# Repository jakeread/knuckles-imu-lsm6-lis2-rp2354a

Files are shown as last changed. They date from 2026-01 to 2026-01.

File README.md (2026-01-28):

# Knuckles Accelerometer Module

> An IMU using the LSM6DSV16X accelerometer, LIS2MDL magnetometer, and RP2354A microcontroller. 

| | |
| --- | --- |
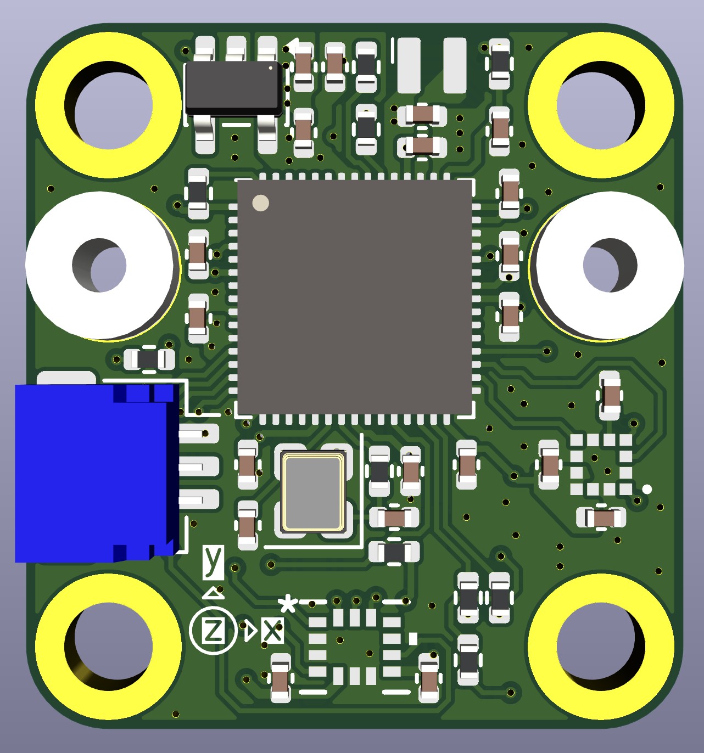
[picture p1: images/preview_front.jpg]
preview_front
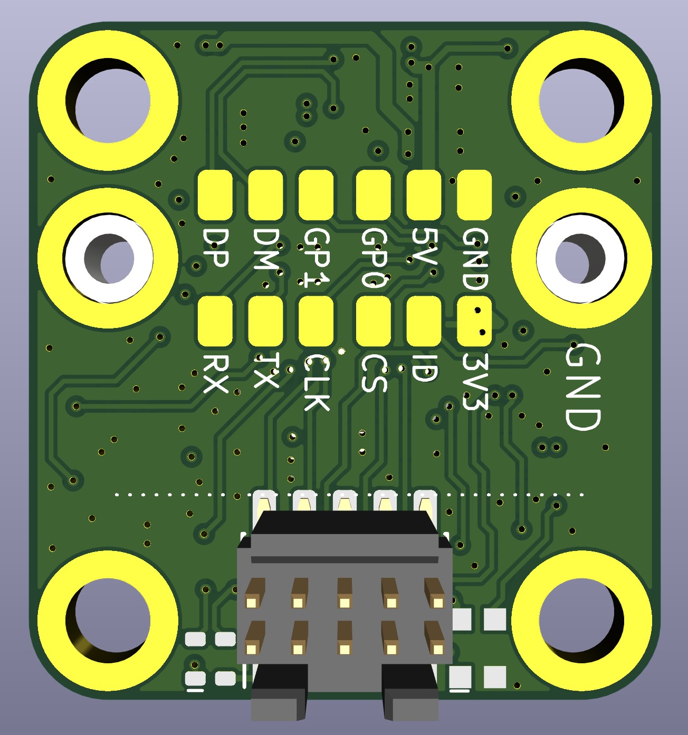
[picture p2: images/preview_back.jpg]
preview_back
|  |  |
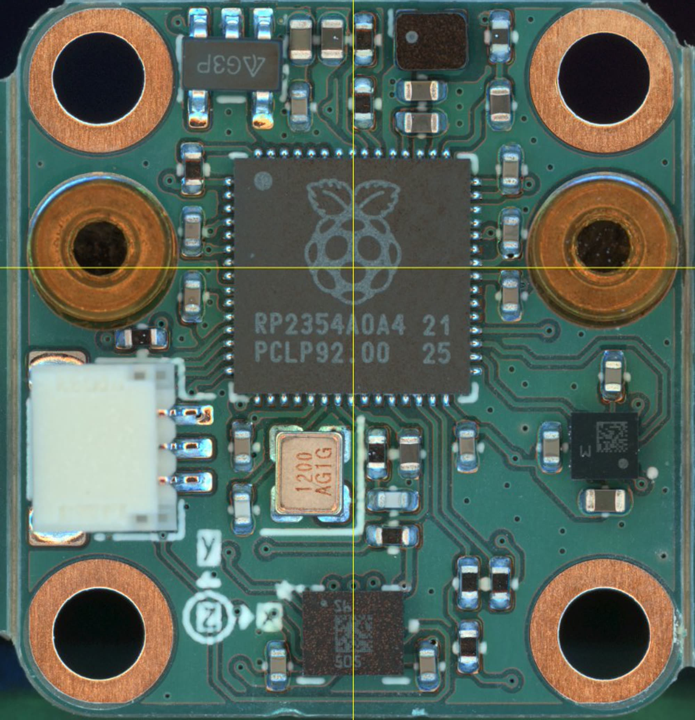
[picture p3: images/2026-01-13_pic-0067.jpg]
fab_front
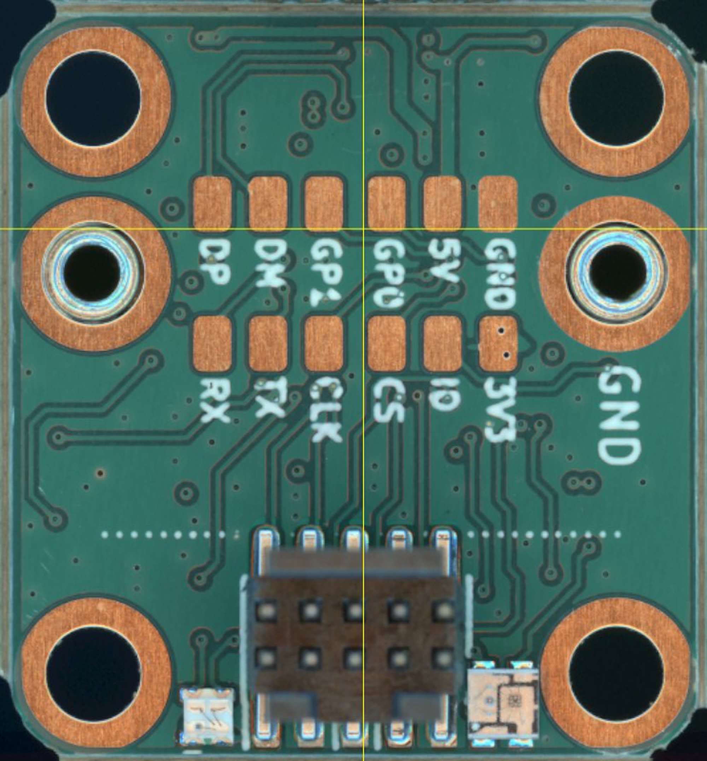
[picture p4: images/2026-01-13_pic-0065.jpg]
fab_back
|  |  |
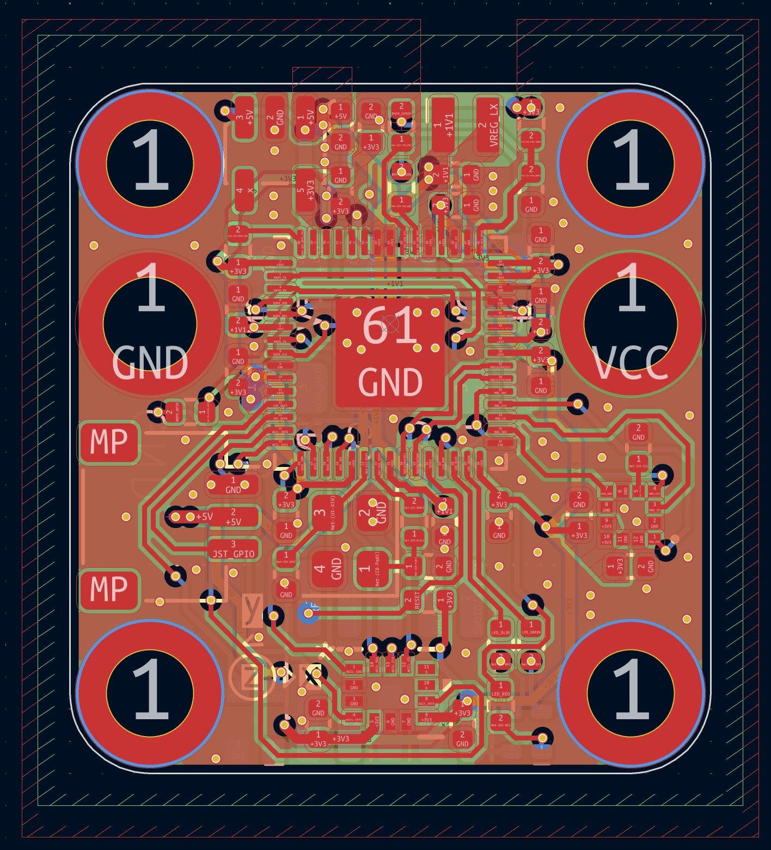
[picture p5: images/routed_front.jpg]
routed_front
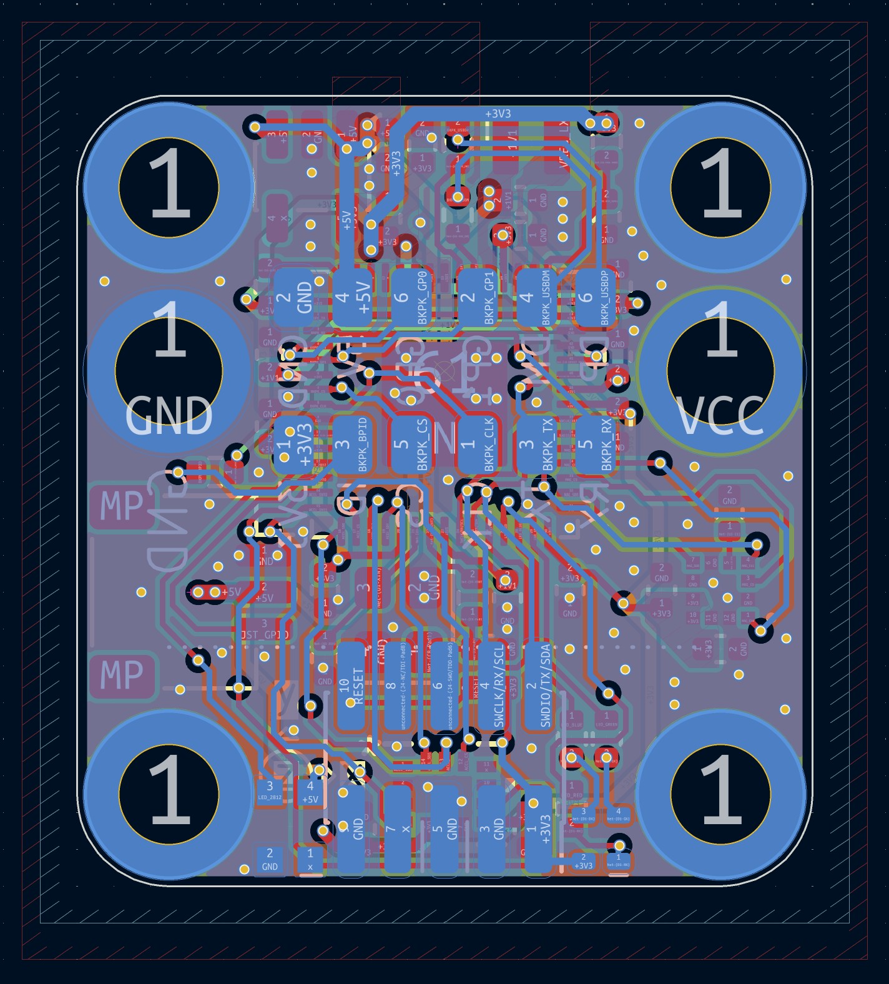
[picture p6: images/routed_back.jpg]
routed_back
|  |  |

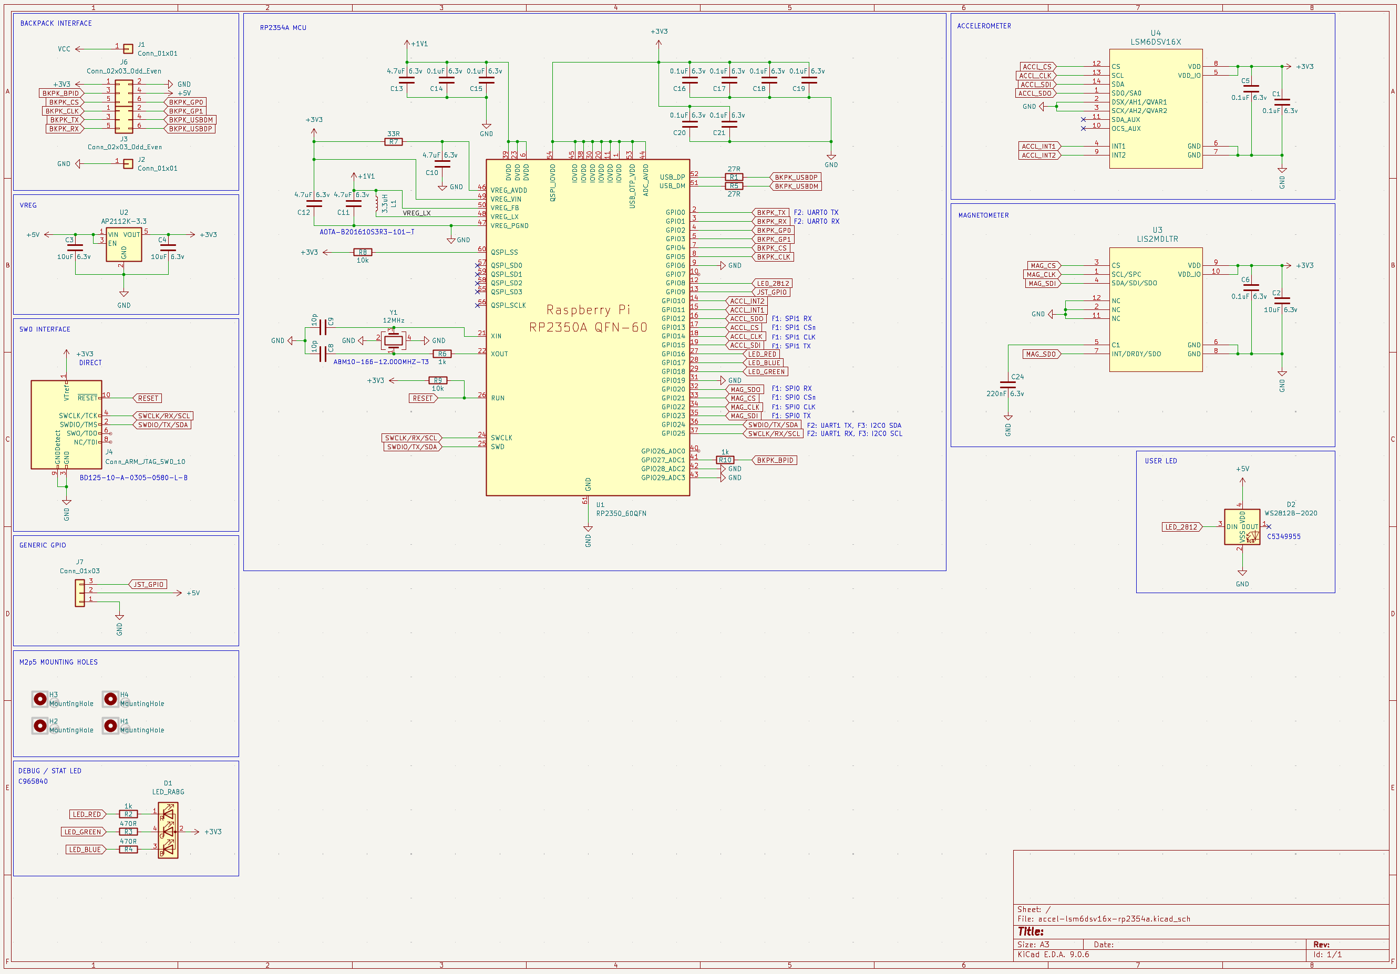
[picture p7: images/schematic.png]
schematic
  

## Functional Description

This is an IMU module that pairs the LSM6DSV16X accelerometer with an LIS2MDL magnetometer, using an RP2354A microcontroller. It is part of a larger family of modular circuits that I call `knuckles` and are used to build machine controllers. The `knuckles` system is not yet public. This IMU will be used to improve kinematic and frequency response models with higher frequency data than I can currently capture. 

The RP2354A is connected to the LSM6 and LIS2 via two indepentent SPI busses, and the LSM6's two interrupt lines are also routed back to the RP2354A. The board also includes an RGB LED (using GPIOs) for RTOS status indication, and a WS2812-based RGB LED for application status. 

The board is programmed with a standard 10-pin SWD connector. Communication is done through a `backpack` connection, which interfaces to modular PHY circuits; this is part of the `knuckles` system: the interface can be extended for UART, USB, CAN, Ethernet, or Wireless links. 

I have also included a generic GPIO output on a JST-SH connector for adhoc applications (it may be useful and there was space). 

## Enclosure

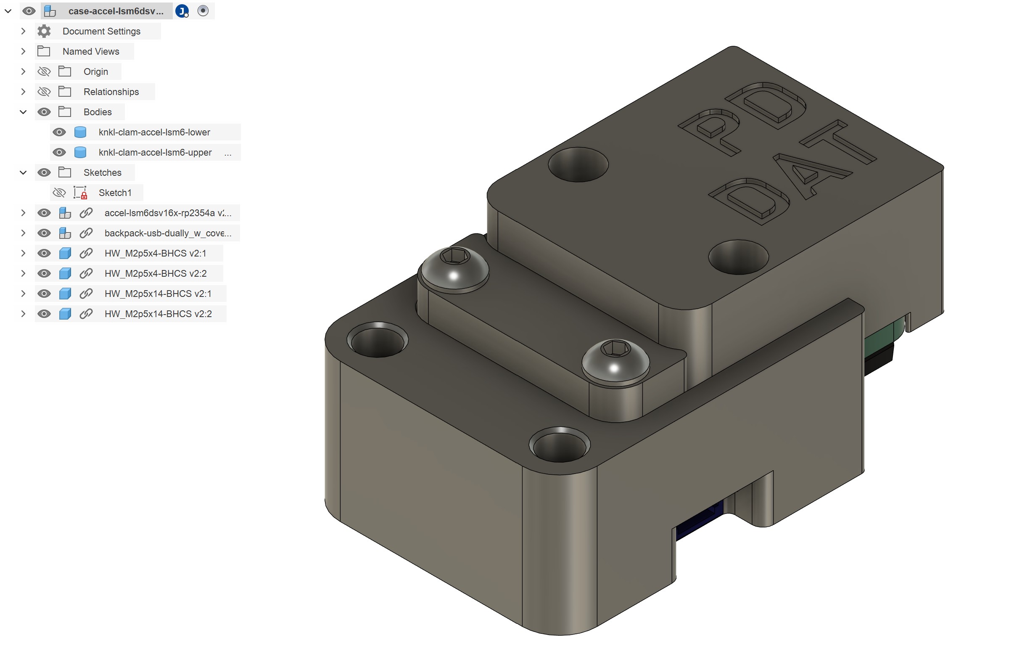
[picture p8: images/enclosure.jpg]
enclosure


The board can be mounted directly into a machine and enclosed there, or mounted into this enclosure and attached externally anywhere. This is intended to be printed in PETG and uses M2.5 hardware. 

## TODO

- bring up and test firmware

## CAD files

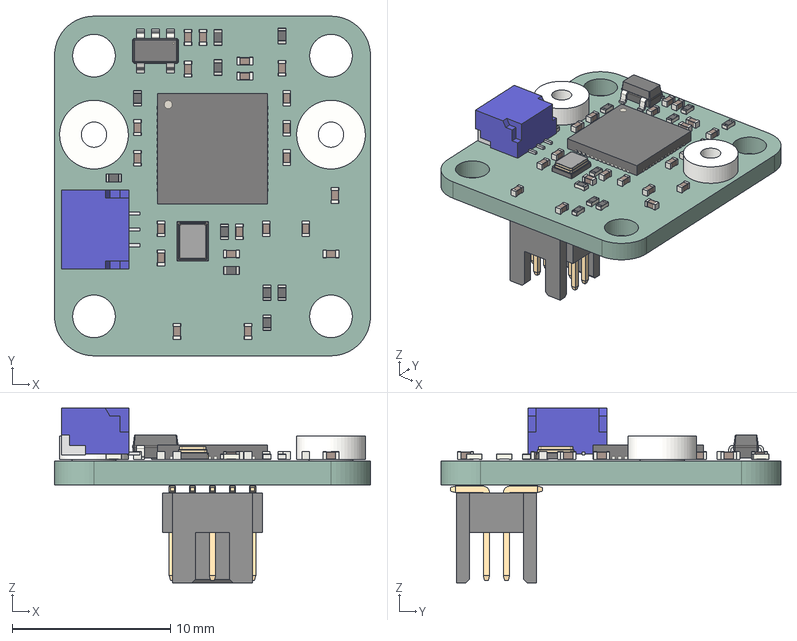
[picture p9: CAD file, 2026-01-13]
cad/accel-lsm6dsv16x-rp2354a.step
20.0 x 21.5 x 11.1 mm
C_0402_1005Metric x 21
R_0402_1005Metric x 10
Wurth_WA-SMST_M2_Thread_1.5mm_9774015243R x 2
QFN-56-1EP_7x7mm_P0.4mm_EP5.6x5.6mm
Crystal_SMD_2520-4Pin_2.5x2.0mm
SOT-23-5
JST_SH_SM03B-SRSS-TB_1x03-1MP_P1.00mm_Horizontal
PinHeader_2x05_P1.27_Vertical_SMD_Shrouded_BD125-10-A-0305-0580-L-B
accel-lsm6dsv16x-rp2354a_PCB

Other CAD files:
cad/case-accel-lsm6dsv16x-rp2354a.f3z

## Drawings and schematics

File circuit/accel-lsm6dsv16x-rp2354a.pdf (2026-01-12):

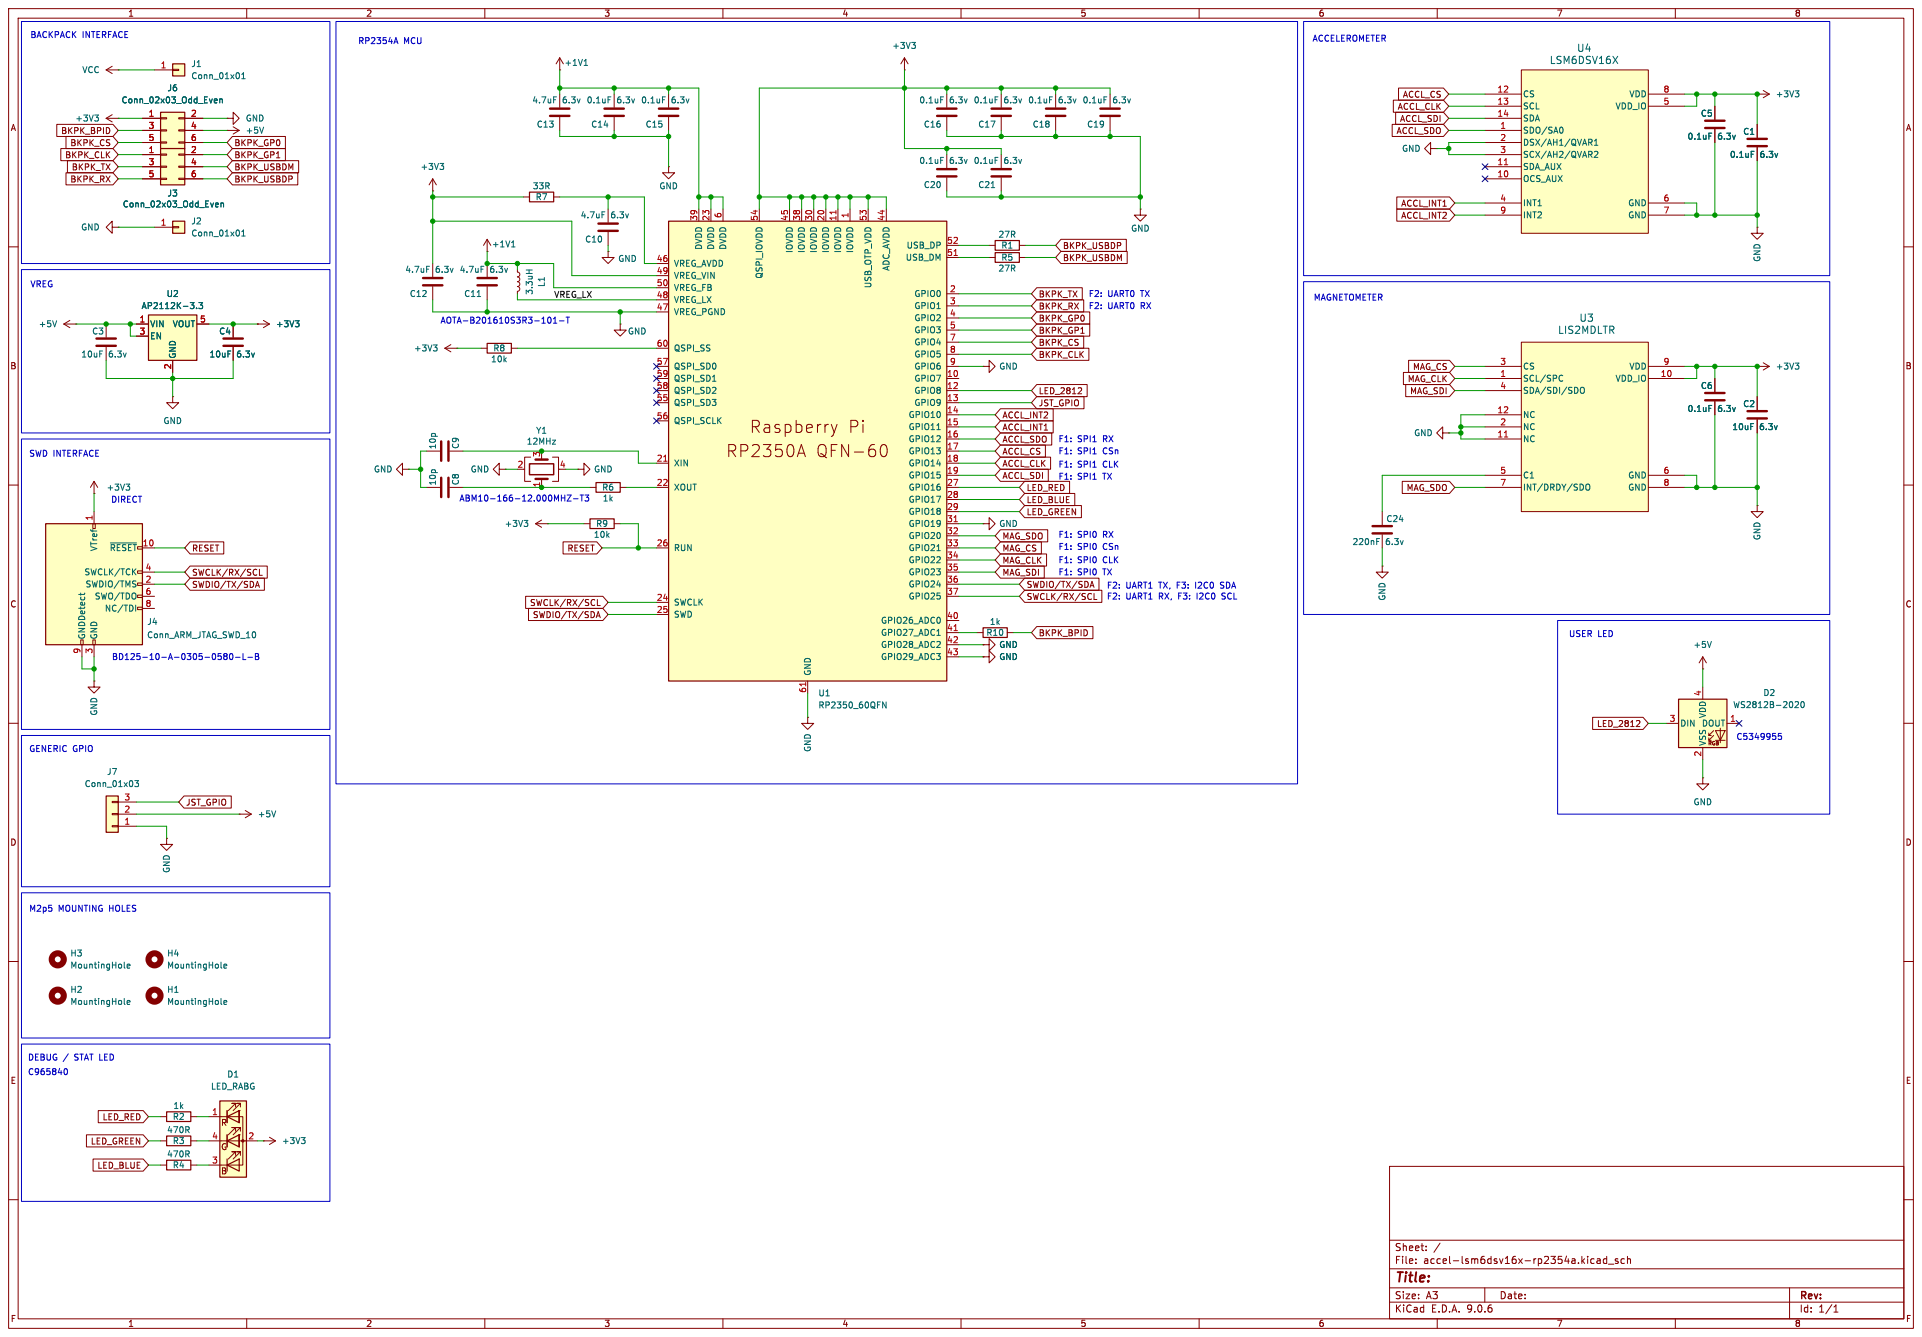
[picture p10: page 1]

ACCL_INT2 SWCLK/RX/SCL SWDIO/TX/SDA

6 QSPI_IOVDD 54 IOVDD 45 IOVDD 38 GND 61 IOVDD 30 IOVDD 20 IOVDD 11 IOVDD

2 VOUT 5 U2 AP2112K-3.3 +5V GND
F2: UART0 RX GENERIC GPIO
ABM10-166-12.000MHZ-T3 AOTA-B201610S3R3-101-T M2p5 MOUNTING HOLES DEBUG / STAT LED

3 ~{RESET}10 SWCLK/TCK 4 SWDIO/TMS 2 SWO/TDO 6 NC/TDI 8

Id: 1/1 Title: File: accel-lsm6dsv16x-rp2354a.kicad_sch Sheet: /

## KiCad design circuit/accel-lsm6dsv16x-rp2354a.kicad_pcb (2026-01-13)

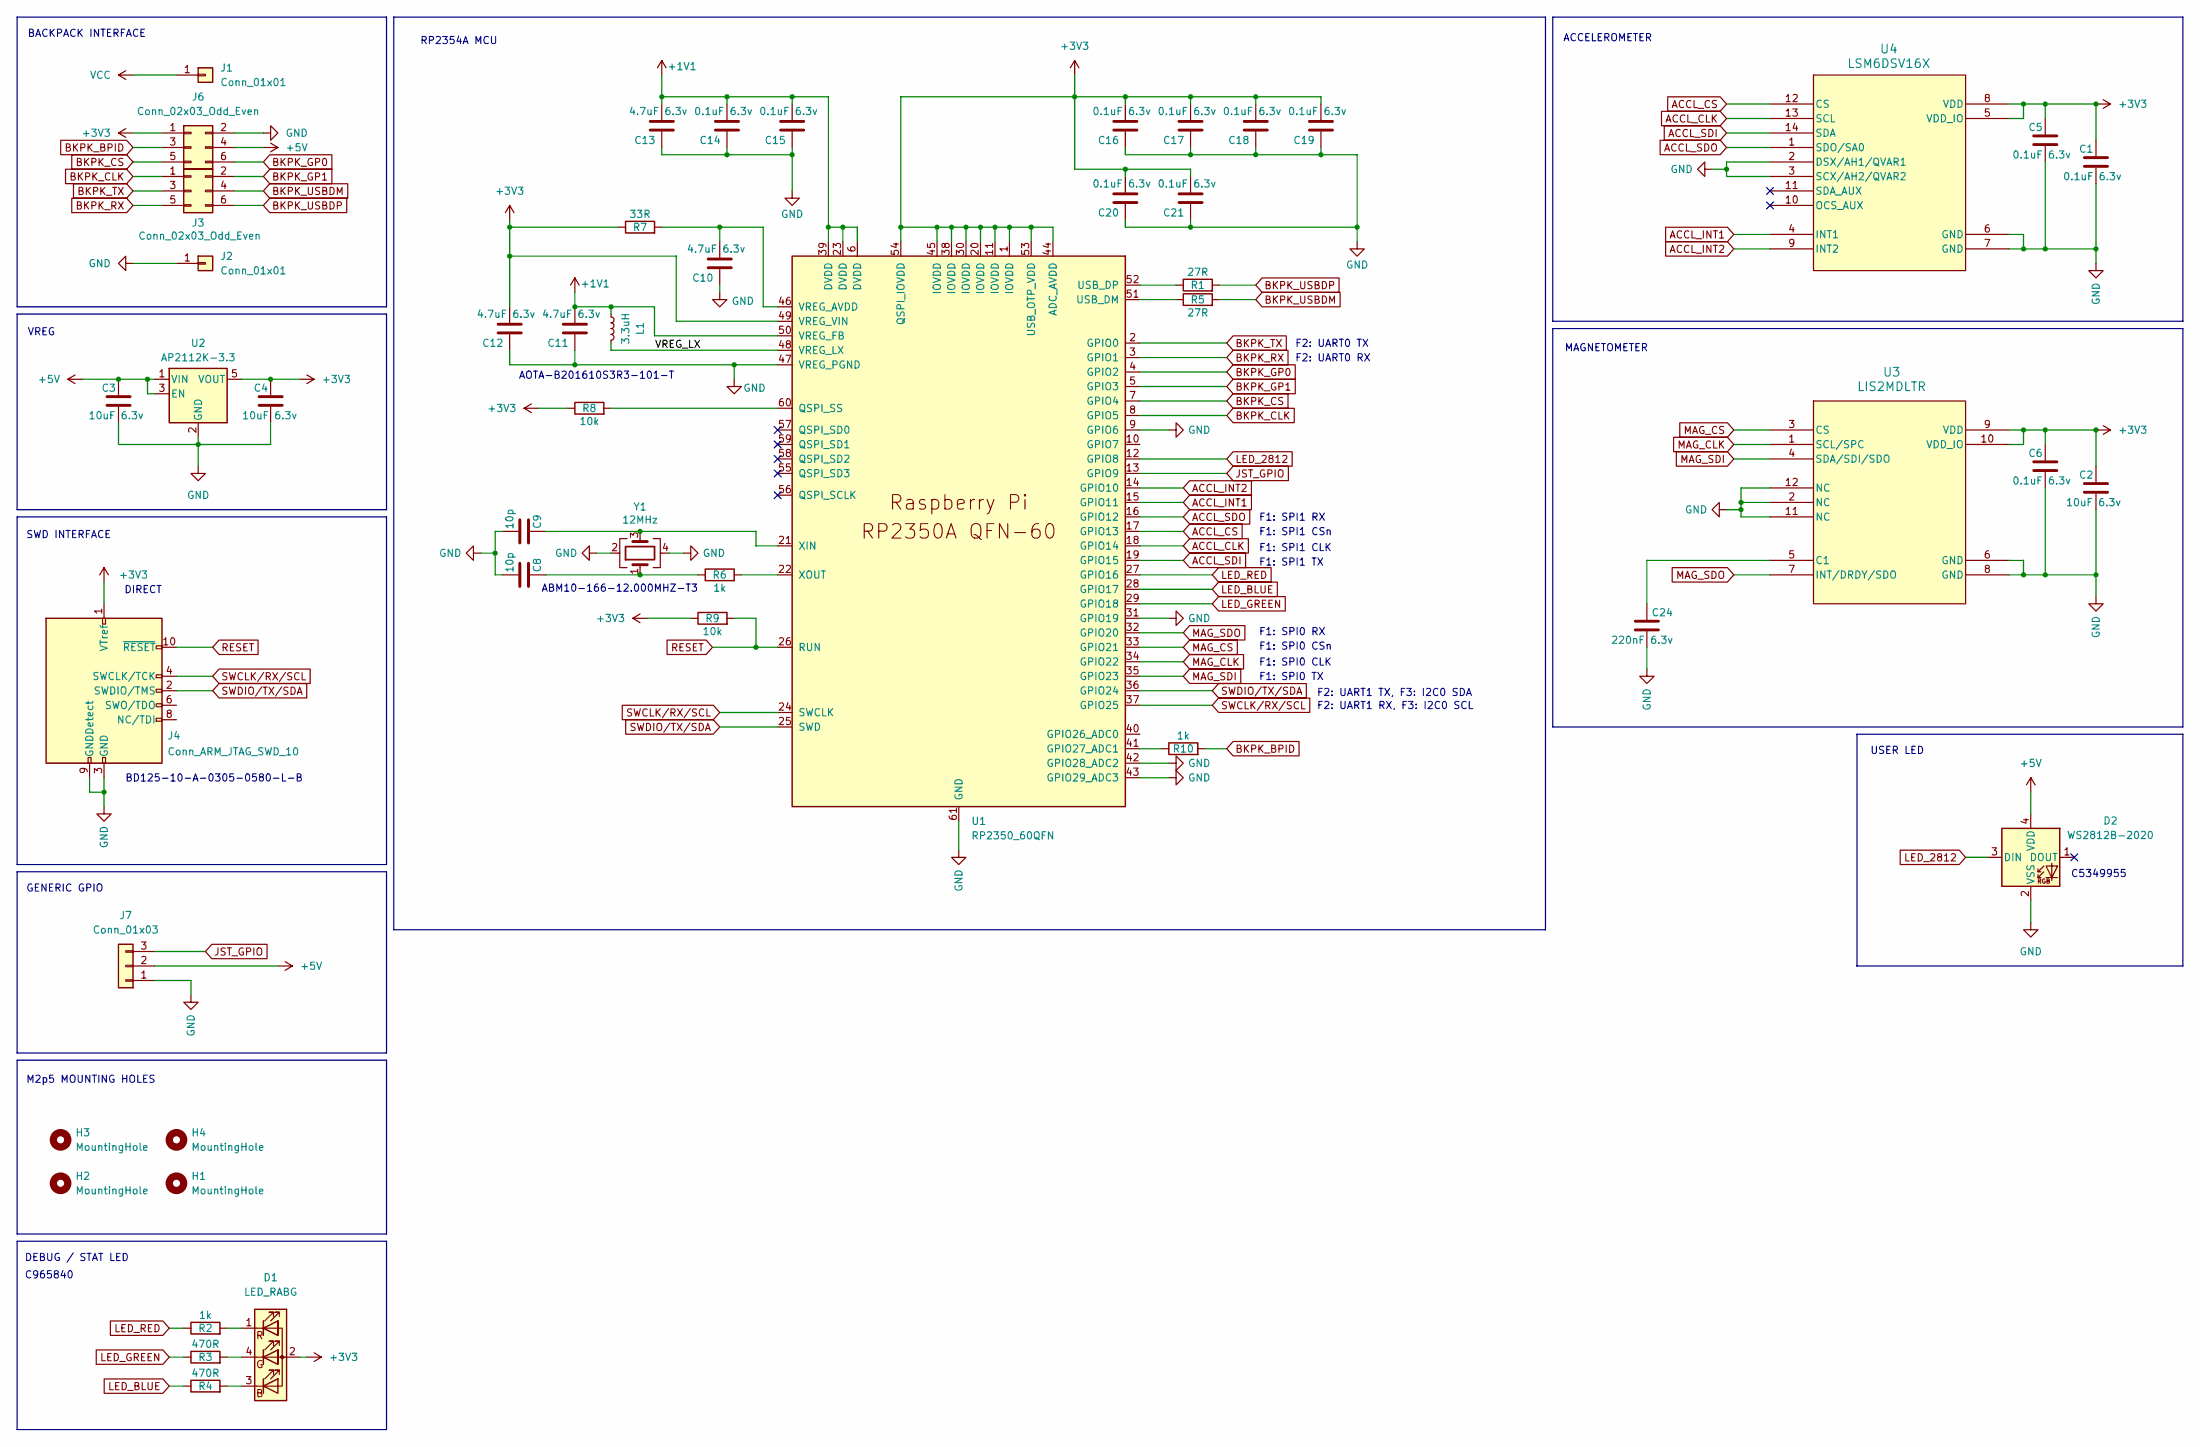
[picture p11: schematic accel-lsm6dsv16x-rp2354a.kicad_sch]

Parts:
C1, C5, C6, C14, C15, C16, C17, C18, C19, C20, C21: 0.1uF 6.3v; C_0402_1005Metric; MPN CC0402KRX7R5BB104
C2, C3, C4: 10uF 6.3v; C_0402_1005Metric; MPN MSASJ105CB5106MFNQ1D
C8, C9: 10p; C_0402_1005Metric; MPN CC0402JRNPO9BN100
C10, C11, C12, C13: 4.7uF 6.3v; C_0402_1005Metric; MPN CC0402MRX5R5BB475
C24: 220nF 6.3v; C_0402_1005Metric; MPN CC0402MRX5R5BB224
D1: LED_RABG; LED_RGB_1615; MPN XL-1615RGBC-RF; LCSC Part # C965840
D2: WS2812B-2020; LED_WS2812B-2020_PLCC4_2.0x2.0mm; MPN XL-2020RGBC-2812B; LCSC Part # C5349955
H1, H2, H3, H4: MountingHole; MountingHole_M2.5_Corner
J1, J2: Conn_01x01; Wurth_WA-SMST_M2_Thread_1.5mm_9774015243R; MPN SMTWEM215STR; DigiKey Part # 732-7069-6-ND
J3: Conn_02x03_Odd_Even; SpringTarget_2x03_Molex_0788641001; LCSC Part # DNP
J4: Conn_ARM_JTAG_SWD_10; PinHeader_2x05_P1.27mm_Vertical_SMD_Shrouded_BD125-10-A-030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; MPN FTSH-105-01-F-DV-K; LCSC Part # C5382952
J6: Conn_02x03_Odd_Even; SpringTarget_2x03_Molex_0788641001; Digikey Part # DNP
J7: Conn_01x03; JST_SH_SM03B-SRSS-TB_1x03-1MP_P1.00mm_Horizontal; MPN SM03B-SRSS-TB(LF)(SN); Digikey Part # 455-SM03B-SRSS-TBCT-ND
L1: 3.3uH; L_pol_2016; MPN AOTA-B201610S3R3-101-T; Digikey Part # AOTA-B201610S3R3-101-T
R1, R5: 27R; R_0402_1005Metric; MPN RC0402FR-0727RL
R2, R6, R10: 1k; R_0402_1005Metric; MPN RC0402FR-071KL
R3, R4: 470R; R_0402_1005Metric; MPN RC0402FR-07470RL
R7: 33R; R_0402_1005Metric; MPN RC0402FR-0733RL
R8, R9: 10k; R_0402_1005Metric; MPN RC0402FR-0710KL
U1: RP2350_60QFN; RP2350-QFN-60-1EP_7x7_P0.4mm_EP3.4x3.4mm; MPN RP2354A; LCSC Part # C41378174
U2: AP2112K-3.3; SOT-23-5; MPN AP2112K-3.3TRG1; LCSC Part # C51118
U3: LIS2MDLTR; LGA-12_2X2X1_STM; MPN LIS2MDLTR; Digikey Part # LIS2MDLTR
U4: LSM6DSV16X; LGA14_LSM6_STM; MPN LSM6DSV16XTR; Digikey Part # LSM6DSV16XTR
Y1: 12MHz; Crystal_SMD_2520-4Pin_2.5x2.0mm; MPN ABM10-166-12.000MHZ-T3; Digikey Part # 535-13520-1-ND

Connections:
+1V1: C11.2, C13.2, C14.2, C15.2, L1.1, U1.6 (DVDD), U1.23 (DVDD), U1.39 (DVDD), U1.50 (VREG_FB)
+3V3: C1.1, C2.1, C4.1, C5.1, C6.1, C12.2, C16.2, C17.2, C18.2, C19.2, C20.2, C21.2, D1.2 (A), J4.1 (VTref), J6.1, R7.1, R8.1, R9.1, U1.1 (IOVDD), U1.11 (IOVDD), U1.20 (IOVDD), U1.30 (IOVDD), U1.38 (IOVDD), U1.44 (ADC_AVDD), U1.45 (IOVDD), U1.49 (VREG_VIN), U1.53 (USB_OTP_VDD), U1.54 (QSPI_IOVDD), U2.5 (VOUT), U3.9 (VDD), U3.10 (VDD_IO), U4.5 (VDD_IO), U4.8 (VDD)
+5V: C3.1, D2.4 (VDD), J6.4, J7.2, U2.1 (VIN), U2.3 (EN)
/VREG_LX: L1.2, U1.48 (VREG_LX)
ACCL_CLK: U1.18 (GPIO14), U4.13 (SCL)
ACCL_CS: U1.17 (GPIO13), U4.12 (CS)
ACCL_INT1: U1.15 (GPIO11), U4.4 (INT1)
ACCL_INT2: U1.14 (GPIO10), U4.9 (INT2)
ACCL_SDI: U1.19 (GPIO15), U4.14 (SDA)
ACCL_SDO: U1.16 (GPIO12), U4.1 (SDO/SA0)
BKPK_BPID: J6.3, R10.2
BKPK_CLK: J3.1, U1.8 (GPIO5)
BKPK_CS: J6.5, U1.7 (GPIO4)
BKPK_GP0: J6.6, U1.4 (GPIO2)
BKPK_GP1: J3.2, U1.5 (GPIO3)
BKPK_RX: J3.5, U1.3 (GPIO1)
BKPK_TX: J3.3, U1.2 (GPIO0)
BKPK_USBDM: J3.4, R5.2
BKPK_USBDP: J3.6, R1.2
GND: C1.2, C2.2, C3.2, C4.2, C5.2, C6.2, C8.2, C9.2, C10.1, C11.1, C12.1, C13.1, C14.1, C15.1, C16.1, C17.1, C18.1, C19.1, C20.1, C21.1, C24.2, D2.2 (VSS), J2.1, J4.3 (GND), J4.5 (GND), J4.9 (GNDDetect), J6.2, J7.1, U1.9 (GPIO6), U1.31 (GPIO19), U1.42 (GPIO28_ADC2), U1.43 (GPIO29_ADC3), U1.47 (VREG_PGND), U1.61 (GND), U2.2 (GND), U3.2 (NC), U3.6 (GND), U3.8 (GND), U3.11 (NC), U3.12 (NC), U4.2 (DSX/AH1/QVAR1), U4.3 (SCX/AH2/QVAR2), U4.6 (GND), U4.7 (GND), Y1.2, Y1.4
JST_GPIO: J7.3, U1.13 (GPIO9)
LED_2812: D2.3 (DIN), U1.12 (GPIO8)
LED_BLUE: R4.1, U1.28 (GPIO17)
LED_GREEN: R3.1, U1.29 (GPIO18)
LED_RED: R2.1, U1.27 (GPIO16)
MAG_CLK: U1.34 (GPIO22), U3.1 (SCL/SPC)
MAG_CS: U1.33 (GPIO21), U3.3 (CS)
MAG_SDI: U1.35 (GPIO23), U3.4 (SDA/SDI/SDO)
MAG_SDO: U1.32 (GPIO20), U3.7 (INT/DRDY/SDO)
unnamed: C8.1, R6.1, Y1.1
unnamed: D1.3 (BK), R4.2
unnamed: D1.4 (GK), R3.2
unnamed: D1.1 (RK), R2.2
unnamed: R10.1, U1.41 (GPIO27_ADC1)
unnamed: R8.2, U1.60 (QSPI_SS)
unnamed: R5.1, U1.51 (USB_DM)
unnamed: R1.1, U1.52 (USB_DP)
unnamed: C10.2, R7.2, U1.46 (VREG_AVDD)
unnamed: C9.1, U1.21 (XIN), Y1.3
unnamed: R6.2, U1.22 (XOUT)
unnamed: C24.1, U3.5 (C1)
RESET: J4.10 (~RESET), R9.2, U1.26 (RUN)
SWCLK/RX/SCL: J4.4 (SWCLK/TCK), U1.24 (SWCLK), U1.37 (GPIO25)
SWDIO/TX/SDA: J4.2 (SWDIO/TMS), U1.25 (SWD), U1.36 (GPIO24)
VCC: J1.1

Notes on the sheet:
C965840
F1: SPI0 CSn
RP2354A MCU
C5349955
M2p5 MOUNTING HOLES
F2: UART1 RX, F3: I2C0 SCL
F1: SPI1 CSn
BD125-10-A-0305-0580-L-B
GENERIC GPIO
USER LED
MAGNETOMETER
F1: SPI1 TX
DIRECT
F1: SPI0 RX
VREG
F1: SPI0 CLK
DEBUG / STAT LED
F1: SPI1 RX
F2: UART0 RX
SWD INTERFACE
F2: UART0 TX
F1: SPI0 TX
BACKPACK INTERFACE
F1: SPI1 CLK
ABM10-166-12.000MHZ-T3
AOTA-B201610S3R3-101-T
F2: UART1 TX, F3: I2C0 SDA
ACCELEROMETER

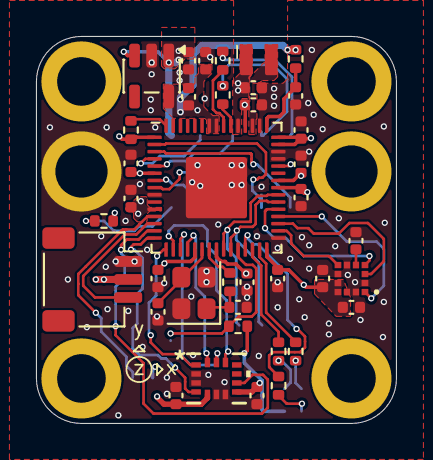
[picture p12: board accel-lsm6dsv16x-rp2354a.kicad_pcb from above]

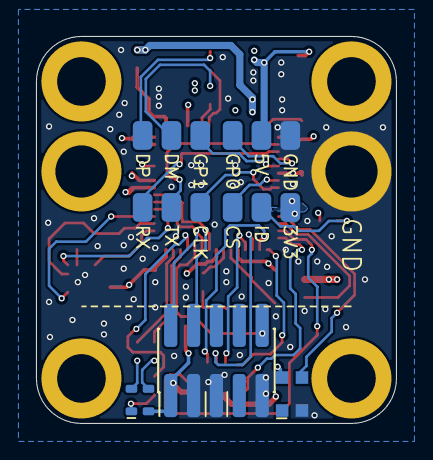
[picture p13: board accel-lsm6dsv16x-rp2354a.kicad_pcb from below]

Board: 4 copper layers, 20.0 x 21.5 mm, 49 parts (5 on the bottom side), 44 nets.

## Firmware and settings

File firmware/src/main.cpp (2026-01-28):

#include "board_hal.h"
#include "SparkFun_LSM6DSV16X.h"
#include <SPI.h>

// TODO
// notes in `maxl-dev/log/2025-11_accelerometer` 

// -------------------------------------------------------- LSM

SparkFun_LSM6DSV16X_SPI lsm;

// -------------------------------------------------------- core 0 for co-mmunication 

void setup() {
  return;

  // normie serial stuff, 
  Serial.begin(); 
  delay(1000);

  // setup the arduino-style SPI interface... 
  SPI.setRX(PIN_LSM_SPI_MISO);
  SPI.setTX(PIN_LSM_SPI_MOSI);
  SPI.setSCK(PIN_LSM_SPI_CLK);
  SPI.setCS(PIN_LSM_SPI_CS);
  pinMode(PIN_LSM_SPI_CS, OUTPUT);
  digitalWrite(PIN_LSM_SPI_CS, HIGH);
  SPI.begin();

  // lsm has this implicitly... ffs, so just
  if(!lsm.begin(PIN_LSM_SPI_CS)){
    Serial.println("lsm.begin fails...");
    return;
  }

  lsm.deviceReset();
  while(!lsm.getDeviceReset()){
    Serial.println("lsm.getDeviceReset() ...");
    delay(1);
  }

  // don't update accel, gyro until read 
  lsm.enableBlockDataUpdate();

  // rates, ranges
  lsm.setAccelDataRate(LSM6DSV16X_ODR_AT_480Hz);
  lsm.setAccelFullScale(LSM6DSV16X_8g);
  lsm.setGyroDataRate(LSM6DSV16X_ODR_AT_480Hz);
  lsm.setGyroFullScale(LSM6DSV16X_250dps);

  // filter ?
  lsm.enableFilterSettling();
  lsm.enableAccelLP2Filter();
  lsm.setAccelLP2Bandwidth(LSM6DSV16X_XL_STRONG);
  lsm.enableGyroLP1Filter();
  lsm.setGyroLP1Bandwidth(LSM6DSV16X_GY_ULTRA_LIGHT);
}

sfe_lsm_data_t data_accel;
sfe_lsm_data_t data_gyro;

void loop() {
  return;
  digitalWrite(PIN_LED_R, !digitalRead(PIN_LED_R));

  lsm.getAccel(&data_accel);
  lsm.getGyro(&data_gyro);

  Serial.println("\tAX: " + String(data_accel.xData, 3) + "\tAY: " + String(data_accel.yData, 3) + "\tAZ: " + String(data_accel.zData, 3));
  Serial.println("\tGX: " + String(data_gyro.xData, 3) + "\tGY: " + String(data_gyro.yData, 3) + "\tGZ: " + String(data_gyro.zData, 3));

  // 
  delay(100);
}

/// 

void setup1(){
  pinMode(PIN_LED_R, OUTPUT); digitalWrite(PIN_LED_R, HIGH);
  pinMode(PIN_LED_G, OUTPUT); digitalWrite(PIN_LED_G, HIGH);
  pinMode(PIN_LED_B, OUTPUT); digitalWrite(PIN_LED_B, HIGH);
  analogWriteResolution(USE_PWM_RES_BITS);
}

void loop1(){
  // le blink 
  // digitalWrite(PIN_LED_R, !digitalRead(PIN_LED_R));
  digitalWrite(PIN_LED_G, !digitalRead(PIN_LED_G));
  // digitalWrite(PIN_LED_B, !digitalRead(PIN_LED_B));
  delay(100);
}

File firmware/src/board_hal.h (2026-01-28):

#ifndef BOARD_HAL_H_
#define BOARD_HAL_H_ 

// stub, cribbed from prior xiao version 

#define PIN_LED_USER_WS2812 12

#define PIN_LED_R           16
#define PIN_LED_G           18
#define PIN_LED_B           17

// LSM6DSV16X
#define PIN_LSM_SPI_CS      13 // F1: SPI1
#define PIN_LSM_SPI_MOSI    15 // F1: SPI1
#define PIN_LSM_SPI_MISO    12 // F1: SPI1
#define PIN_LSM_SPI_CLK     14 // F1: SPI1
#define PIN_LSM_INT1        11
#define PIN_LSM_INT2        10

// LIS2MDLTR
#define PIN_MAG_SPI_CS      21 // F1: SPI0
#define PIN_MAG_SPI_MOSI    23 // F1: SPI0
#define PIN_MAG_SPI_MISO    20 // F1: SPI0
#define PIN_MAG_SPI_CLK     22 // F1: SPI0

// https://docs.sparkfun.com/SparkFun_6DoF_LSM6DSV16X/hardware_overview/#gpio
// https://www.raspberrypi.com/documentation/microcontrollers/pico-series.html 

#define USE_PWM_RES_BITS 10 

#endif

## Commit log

2026-01-12 add design files, etc
    [accel-lsm6dsv16x-rp2354a.kicad_pcb, accel-lsm6dsv16x-rp2354a.kicad_sch]
2026-01-13 add circuit cad and enclosure
    [accel-lsm6dsv16x-rp2354a.kicad_pcb, accel-lsm6dsv16x-rp2354a.step, case-accel-lsm6dsv16x-rp2354a.f3z]
